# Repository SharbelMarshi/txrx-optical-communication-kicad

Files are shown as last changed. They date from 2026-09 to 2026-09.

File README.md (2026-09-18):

# A Free Space Optical Communication
This project implements a free-space optical communication link using two separate KiCad-designed boards: a transmitter and a receiver. The transmitter uses an RP2354A microcontroller to frame arbitrary digital payloads into packets and generate $100 \mathrm{kbit/s}$ RZ-OOK modulation for a $650 \mathrm{nm}$ laser module through a level-shifting buffer and an independent hardware safety chain.
The receiver uses a BPW34 photodiode, OPA320 transimpedance amplifier, and TLV3201 comparator to recover the optical pulses and feed them into an RP2354A for decoding, CRC verification, and delivery to the host system.
Both boards include USB-C, UART, SWD, a local $12 \mathrm{MHz}$ crystal, and a $10 \mathrm{MHz}$ SiTime SiT5346 DCTCXO reference. The SiT5346 is connected to the RP2354A through a GPIO/PIO clock input and is controllable over the existing $\text{I²C}$ bus. Each board also exposes a dedicated $1\mathrm{PPS}$ output generated by the RP2354A. The initial target is a stable free-space optical link over approximately $5$ meters.

## Architecture
Two separate $4$ layer boards:
- TX: RP2354A + USB-C + host I/O + $12 \mathrm{MHz}$ crystal + $10 \mathrm{MHz}$ SiT5346 DCTCXO + dedicated $1\mathrm{PPS}$ output + laser driver/safety chain + laser module.
- RX: RP2354A + USB-C + host I/O + $12 \mathrm{MHz}$ crystal + $10 \mathrm{MHz}$ SiT5346 DCTCXO + dedicated $1\mathrm{PPS}$ output + BPW34 / OPA320 / TLV3201 optical receiver + ADC monitor.

### TX
- TX_ROOT
- TX_POWER_USB
- TX_MCU_CLOCK
- TX_HOST_IO
- TX_LASER

### RX
- RX_ROOT
- RX_POWER_USB
- RX_MCU_CLOCK
- RX_HOST_IO
- RX_OPTICAL_AFE
- RX_MONITOR

### TX schamtics:

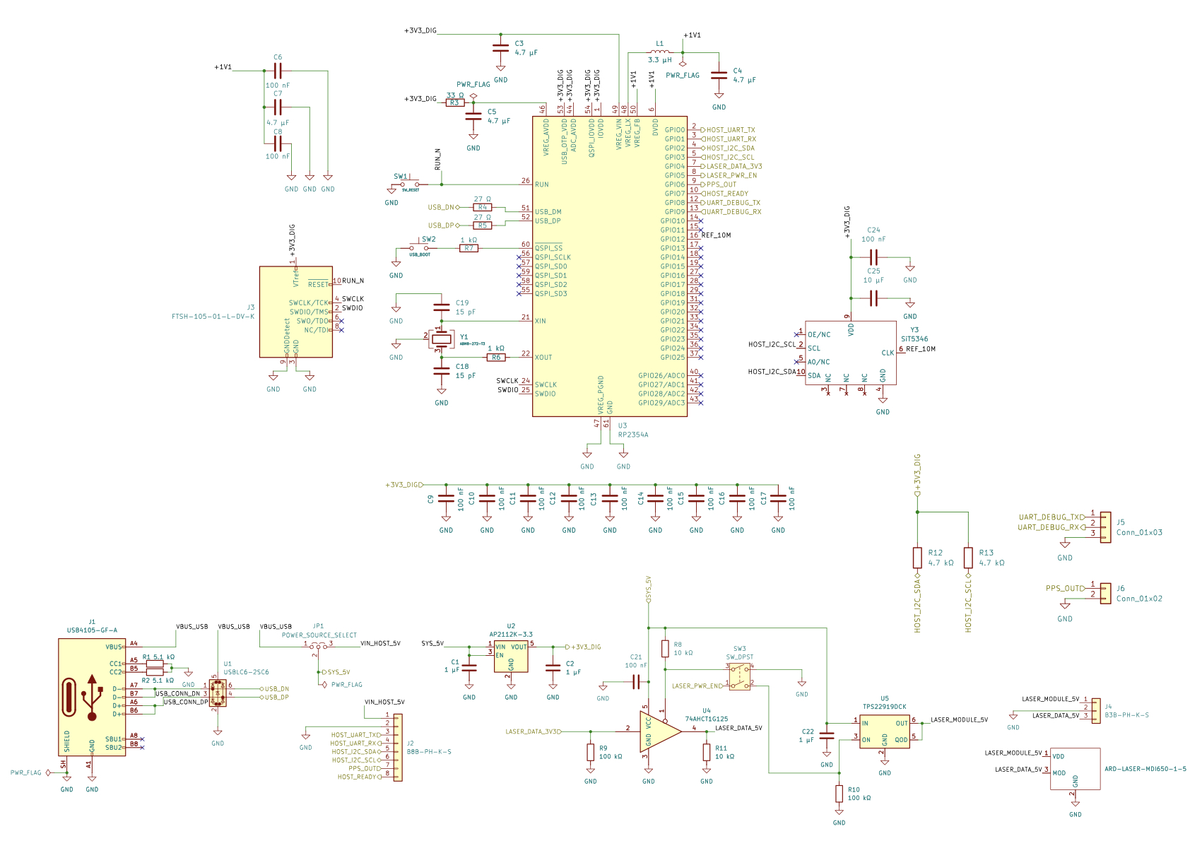
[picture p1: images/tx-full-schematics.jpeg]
schematics


### TX PCB: 

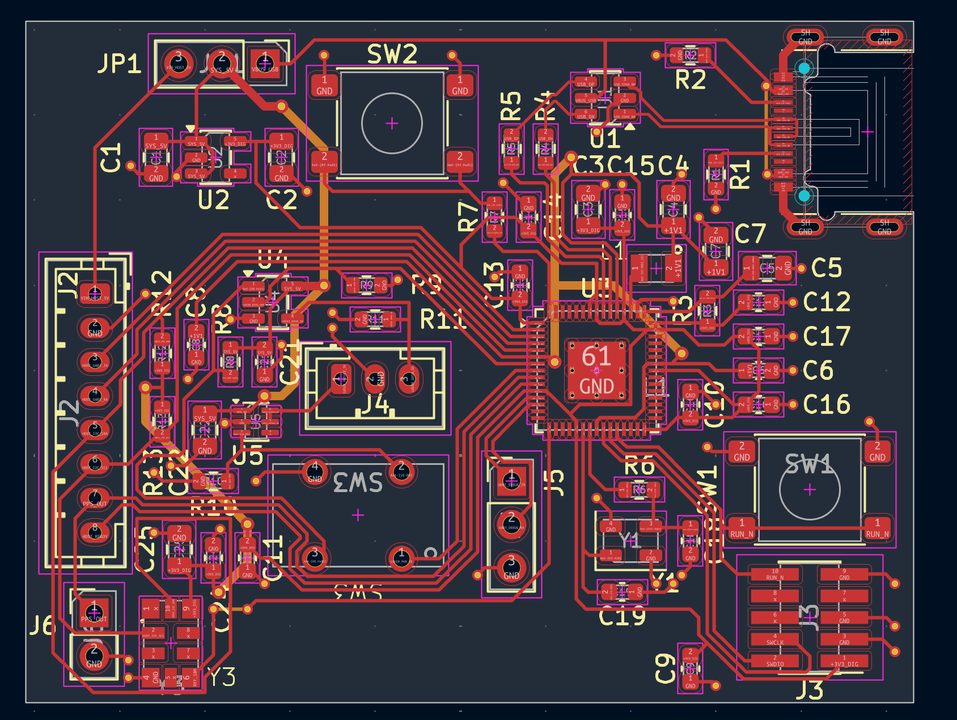
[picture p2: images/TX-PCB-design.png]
pcb design
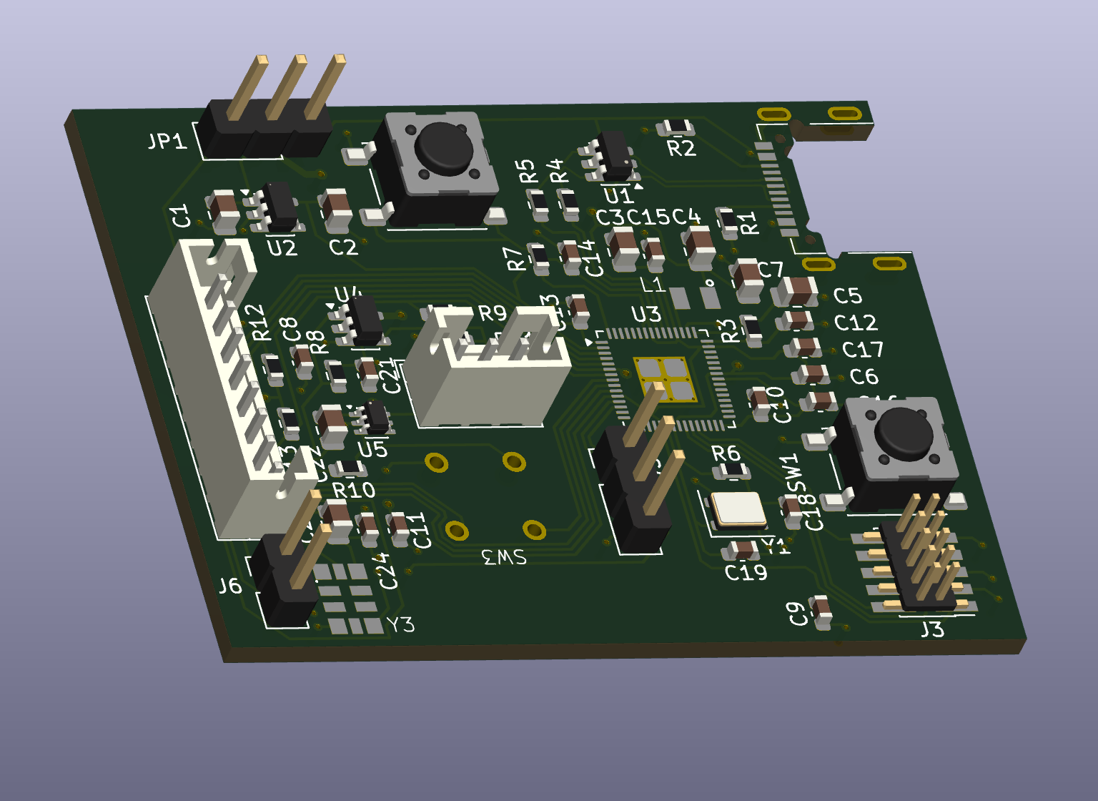
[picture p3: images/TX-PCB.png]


### RX schamtics:

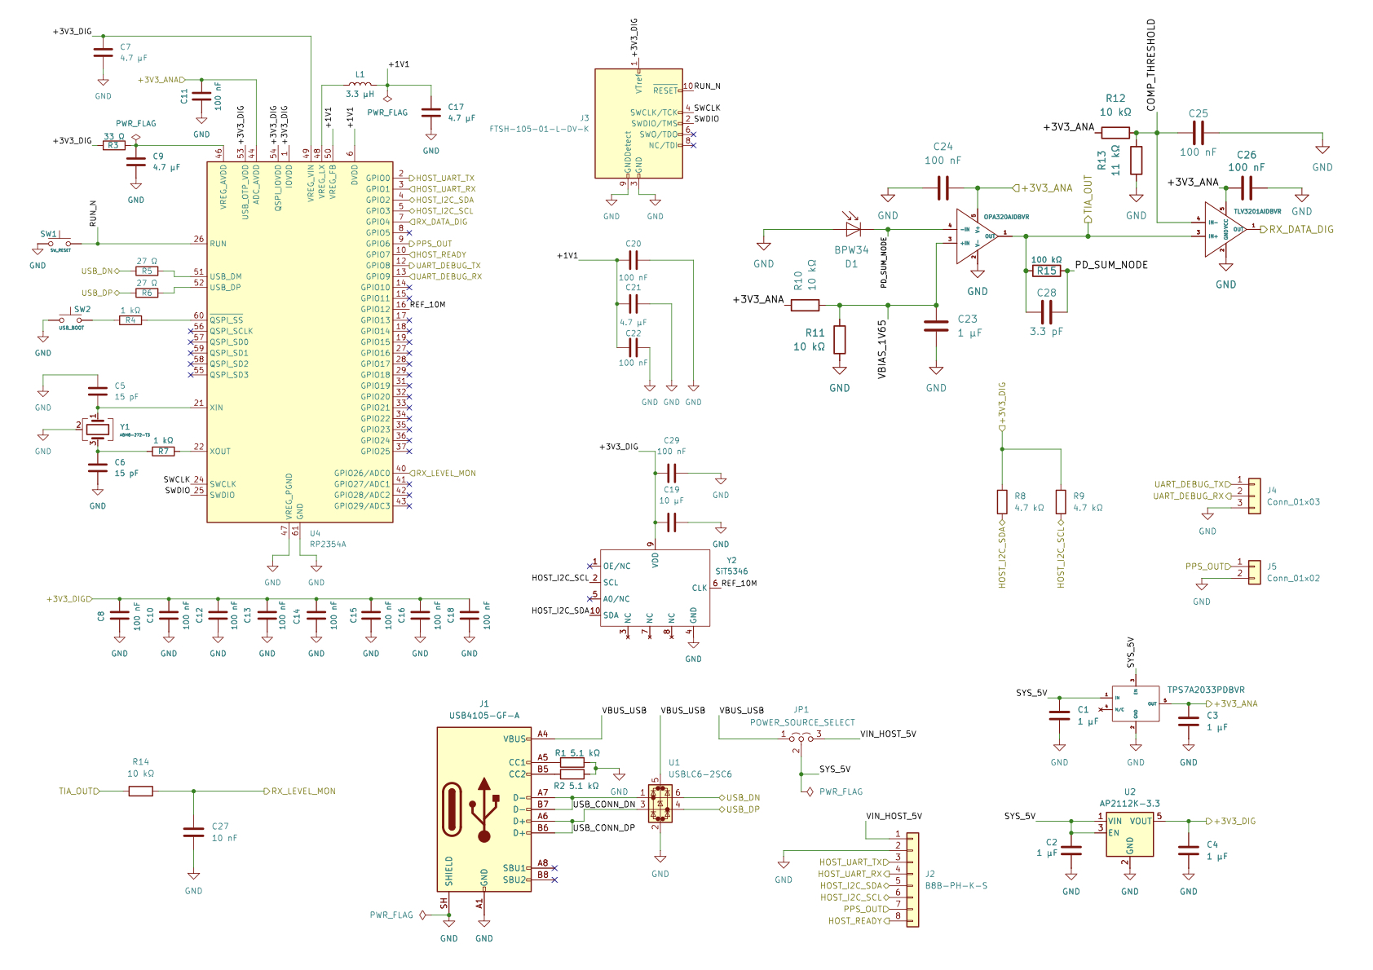
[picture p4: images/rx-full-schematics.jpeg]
schematics


### RX PCB: 

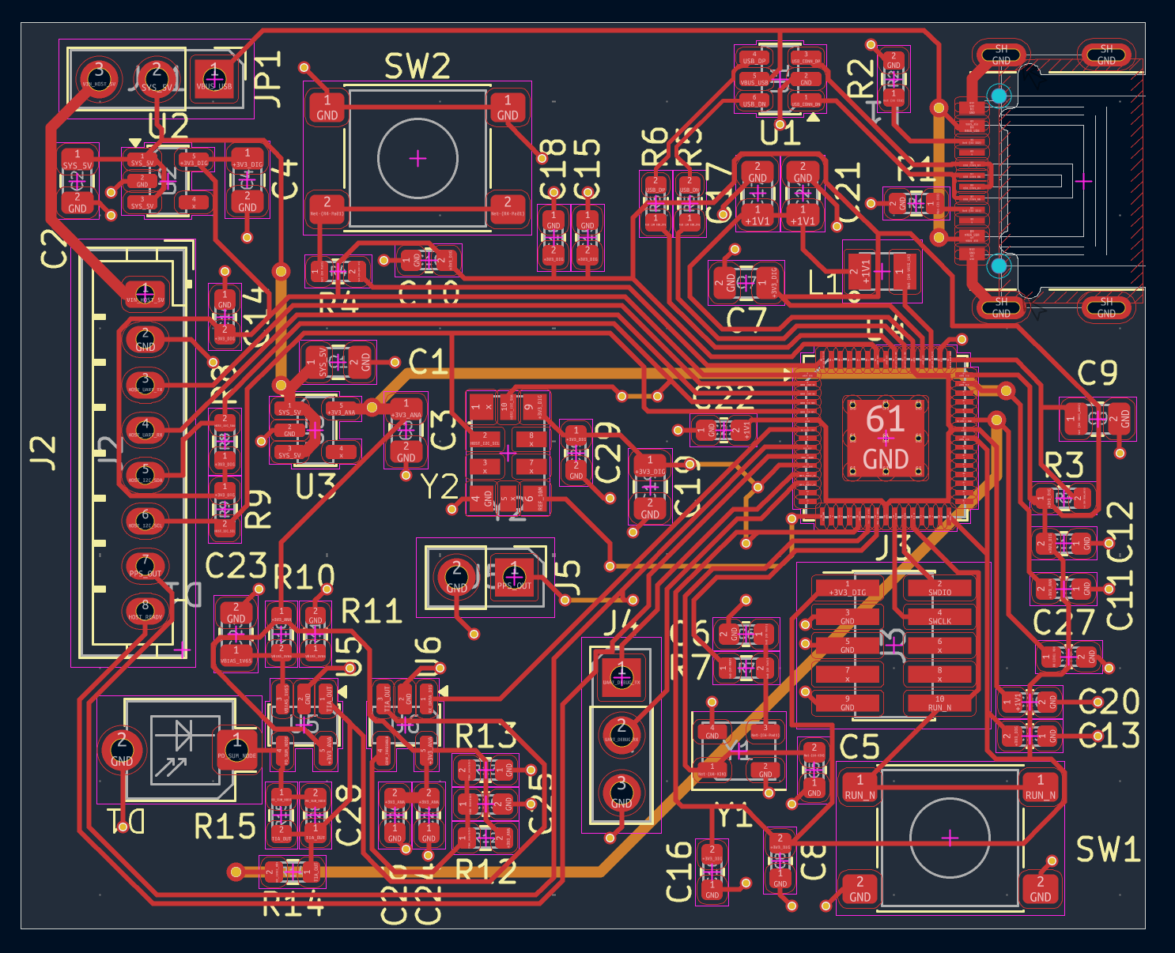
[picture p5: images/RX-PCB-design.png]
pcb design
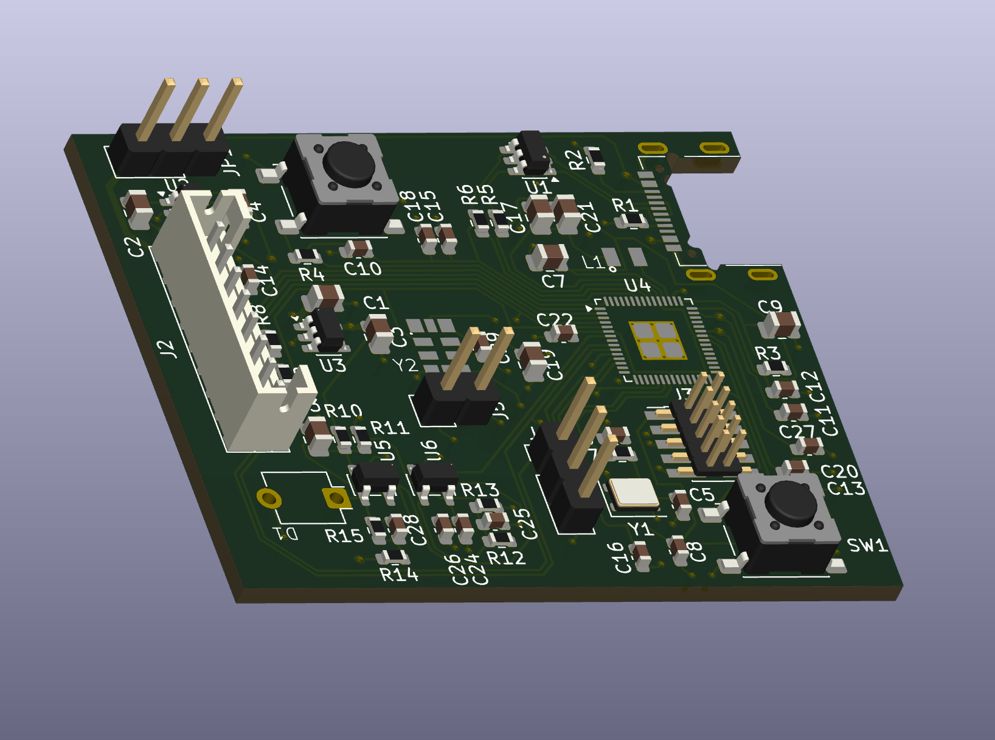
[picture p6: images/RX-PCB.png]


## Library:
### Pre-built Components Compatibility Verfication:

Verified: Symbol and Footprint compatibility: 

1. RP2354A  ✓
2. AP2112K-3.3  ✓
3. SN74AHCT1G125DBVR  ✓
4. TPS22919DCKR  ✓
5. USBLC6-2SC6  ✓
7. REF2033  ✓

### Costum Components:

1. SiT5346 ✓
2. OPA320  ✓
3. TLV3201 ✓
4. BPW34 (custom footprint)  ✓
5. TPS7A2033  (customed symbol) ✓
6. ABM8-272-T3_3225 (custom footprint)  ✓
7. AOTA-B201610S3R3-101-T (custom footprint) ✓
8. ES22MCBE (custom footprint) ✓
9. B3B-PH-K-S ✓
10. B8B-PH-K-S ✓
11. ARD-LASER-MDI650-1-5 ✓
12. FTSH-105-01-L-DV-K ✓
13. USB4105-GF-A ✓

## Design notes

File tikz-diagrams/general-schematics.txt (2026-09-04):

\usetikzlibrary{arrows.meta,positioning,fit}
\begin{tikzpicture}[
    font=\small,
    >=Latex,
    node distance=10mm and 18mm,
    block/.style={
        draw,
        rounded corners,
        thick,
        minimum width=34mm,
        minimum height=11mm,
        align=center
    },
    group/.style={
        draw,
        dashed,
        rounded corners,
        inner sep=6mm
    },
    arrow/.style={
        ->,
        thick
    }
]
\node[block] (hosttx) {Host System};
\node[block, below=of hosttx] (txmcu) {RP2354A Packet + PIO};
\node[block, below=of txmcu] (txbuf) {74AHCT1G125 Buffer};
\node[block, below=of txbuf] (laser) {650 nm Laser Module};
\node[block, right=75mm of hosttx] (hostrx) {Destination Host};
\node[block, below=of hostrx] (rxmcu) {RP2354A Decode + CRC};
\node[block, below=of rxmcu] (comp) {TLV3201 Comparator};
\node[block, below=of comp] (tia) {OPA320 TIA};
\node[block, below=of tia] (pd) {BPW34 Photodiode};
\draw[arrow] (hosttx) -- node[right] {data} (txmcu);
\draw[arrow] (txmcu) -- node[right] {100 kbit/s RZ-OOK} (txbuf);
\draw[arrow] (txbuf) -- (laser);
\draw[arrow, dashed, very thick]
(laser.east) -- node[above, rotate=-16] {Free-space optical link} (pd.west);
\draw[arrow] (pd) -- (tia);
\draw[arrow] (tia) -- (comp);
\draw[arrow] (comp) -- (rxmcu);
\draw[arrow] (rxmcu) -- node[right] {decoded data} (hostrx);
\node[
    group,
    fit=(hosttx)(txmcu)(txbuf)(laser),
    label=above:{\bfseries FSOC\_TX}
] {};

\node[
    group,
    fit=(hostrx)(rxmcu)(comp)(tia)(pd),
    label=above:{\bfseries FSOC\_RX}
] {};
\end{tikzpicture}

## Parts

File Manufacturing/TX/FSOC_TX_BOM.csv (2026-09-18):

Reference | Qty | Value | Footprint | Manufacturer | Description | MPN | JLCPCB Part
C1,C2,C22 | 3 | 1 µF | Capacitor_SMD:C_0805_2012Metric |  | Unpolarized capacitor
C3,C4,C5,C7 | 4 | 4.7 µF | Capacitor_SMD:C_0805_2012Metric |  | Unpolarized capacitor
C6,C8,C9,C10,C11,C12,C13,C14,C15,C16,C17,C21,C24 | 13 | 100 nF | Capacitor_SMD:C_0603_1608Metric |  | Unpolarized capacitor
C18,C19 | 2 | 15 pF | Capacitor_SMD:C_0603_1608Metric |  | Unpolarized capacitor
C25 | 1 | 10 µF | Capacitor_SMD:C_0805_2012Metric |  | Unpolarized capacitor
J1 | 1 | USB4105-GF-A | fsoc_footprints:TYPE-C-31-M-14 | GCT | USB 2.0 Type-C receptacle, 16 contact, top-mount horizontal, through-hole shell stakes | USB4105-GF-A
J2 | 1 | B8B-PH-K-S | Connector_JST:JST_PH_B8B-PH-K_1x08_P2.00mm_Vertical | JST | 8-position JST PH series vertical through-hole wire-to-board header, 2.00 mm pitch | B8B-PH-K-S
J3 | 1 | FTSH-105-01-L-DV-K | fsoc_footprints:FTSH-105-01-L-DV-K | Samtec | 10-pin 1.27 mm keyed vertical SMT header for ARM Cortex SWD/JTAG debug interface | FTSH-105-01-L-DV-K
J4 | 1 | B3B-PH-K-S | Connector_JST:JST_PH_B3B-PH-K_1x03_P2.00mm_Vertical | JST | 3-position JST PH series vertical through-hole wire-to-board header, 2.00 mm pitch | B3B-PH-K-S
J5 | 1 | Conn_01x03 | Connector_PinHeader_2.54mm:PinHeader_1x03_P2.54mm_Vertical |  | Generic connector, single row, 01x03, script generated (kicad-library-utils/schlib/autogen/connector/)
J6 | 1 | Conn_01x02 | Connector_PinHeader_2.54mm:PinHeader_1x02_P2.54mm_Vertical |  | Generic connector, single row, 01x02, script generated (kicad-library-utils/schlib/autogen/connector/)
L1 | 1 | 3.3 µH | fsoc_footprints:AOTA-B201610S3R3-101-T |  | Inductor
MOD1 | 1 | ARD-LASER-MDI650-1-5 |  | Picotronic GmbH | 650 nm 1 mW Class 2 laser module, 5 V, active-high TTL modulation up to 200 kHz | ARD-LASER-MDI650-1-5(10x26)
R1,R2 | 2 | 5.1 kΩ | Resistor_SMD:R_0603_1608Metric |  | Resistor
R3 | 1 | 33 Ω | Resistor_SMD:R_0603_1608Metric |  | Resistor
R4,R5 | 2 | 27 Ω | Resistor_SMD:R_0603_1608Metric |  | Resistor
R6,R7 | 2 | 1 kΩ | Resistor_SMD:R_0603_1608Metric |  | Resistor
R8,R11 | 2 | 10 kΩ | Resistor_SMD:R_0603_1608Metric |  | Resistor
R9,R10 | 2 | 100 kΩ | Resistor_SMD:R_0603_1608Metric |  | Resistor
R12,R13 | 2 | 4.7 kΩ | Resistor_SMD:R_0603_1608Metric |  | Resistor
SW1 | 1 | SW_RESET | Button_Switch_SMD:SW_SPST_PTS645Sx43SMTR92 |  | Push button switch, generic, two pins
SW2 | 1 | USB_BOOT | Button_Switch_SMD:SW_SPST_PTS645Sx43SMTR92 |  | Push button switch, generic, two pins
SW3 | 1 | SW_DPST | fsoc_footprints:ES22MCBE |  | Double Pole Single Throw (DPST) Switch
U1 | 1 | USBLC6-2SC6 | Package_TO_SOT_SMD:SOT-23-6 |  | Very low capacitance ESD protection diode, 2 data-line, SOT-23-6
U2 | 1 | AP2112K-3.3 | Package_TO_SOT_SMD:SOT-23-5 |  | 600mA low dropout linear regulator, with enable pin, 3.8V-6V input voltage range, 3.3V fixed positive output, SOT-23-5
U3 | 1 | RP2354A | Package_DFN_QFN:QFN-60-1EP_7x7mm_P0.4mm_EP3.4x3.4mm_ThermalVias |  | A microcontroller by Raspberry Pi, dual CPU architecture (ARM Cortex-M33 / RISC-V Hazard3), 150MHz, 2MB flash, 520KB SRAM, 12 PIO state machines, VQFN-60
U4 | 1 | 74AHCT1G125 | Package_TO_SOT_SMD:SOT-23-5 |  | Single Buffer Gate Tri-State, Low-Voltage CMOS
U5 | 1 | TPS22919DCK | Package_TO_SOT_SMD:SOT-363_SC-70-6 |  | 1.6V to 5.5 V, 1.5 A, 90-mΩ Self-Protected Load Switch with Controlled Rise Time, SC-70-6
Y1 | 1 | ABM8-272-T3 | fsoc_footprints:ABM8-272-T3_3225 | Abracon | 12 MHz crystal, 10 pF load capacitance, 50 ohm max ESR, 3.2 x 2.5 mm 4-pad SMD | ABM8-272-T3
Y3 | 1 | SiT5346 | fsoc_footprints:SiT5346_5.0x3.2mm_10L | SiTime | SiT5346 DCTCXO, 10.000000 MHz, 3.3 V, LVCMOS, ±0.1 ppm, industrial, I2C-controlled | TBD - SiT5346 10MHz 3.3V LVCMOS DCTCXO | TBD - Global Sourcing if not stocked

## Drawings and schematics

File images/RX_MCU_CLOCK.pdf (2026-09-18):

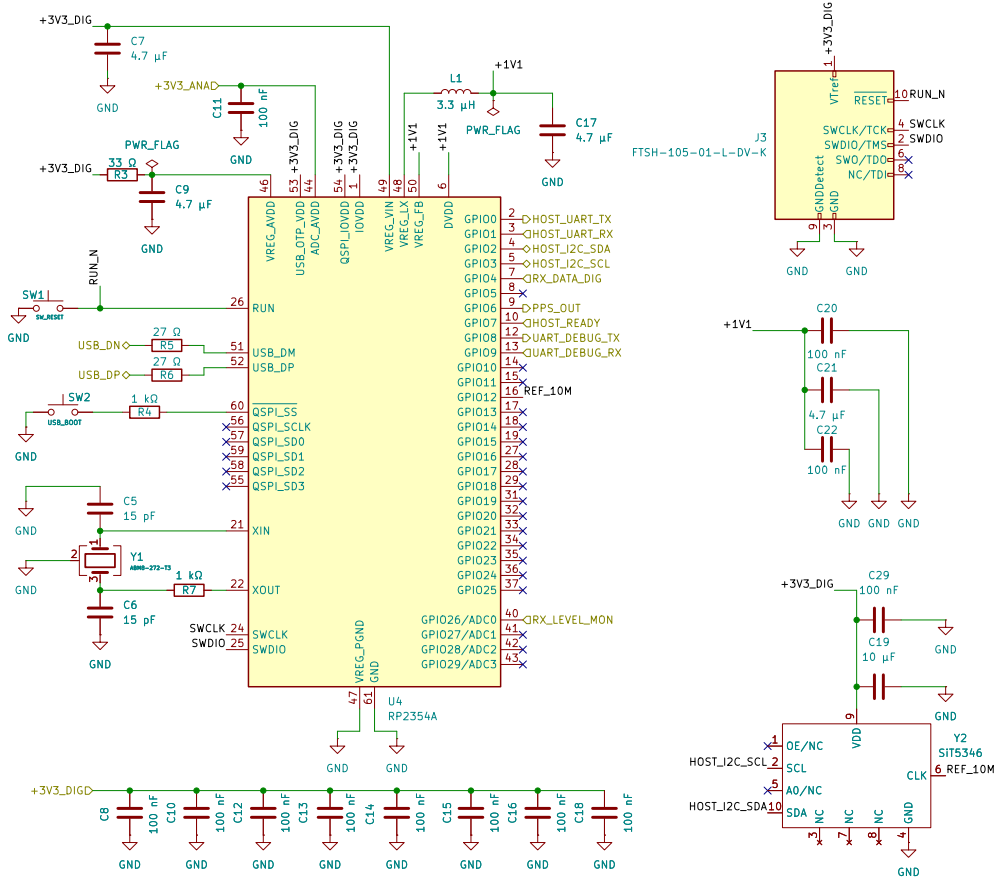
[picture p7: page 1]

100 nF GND GND GND

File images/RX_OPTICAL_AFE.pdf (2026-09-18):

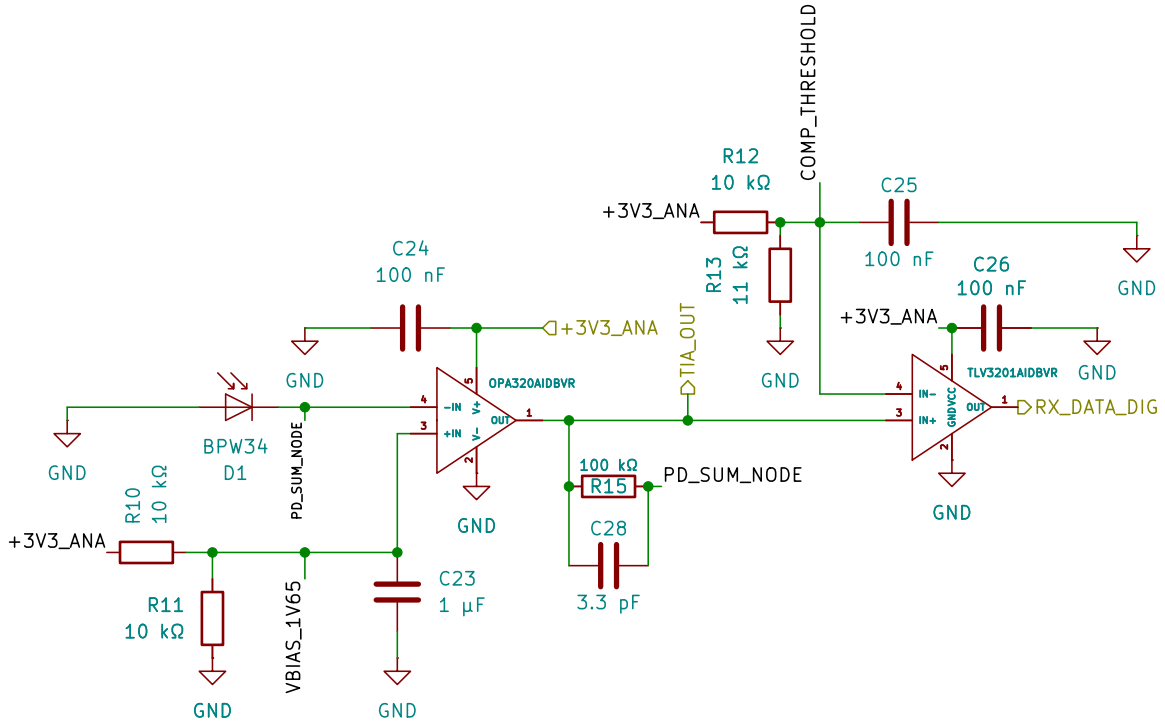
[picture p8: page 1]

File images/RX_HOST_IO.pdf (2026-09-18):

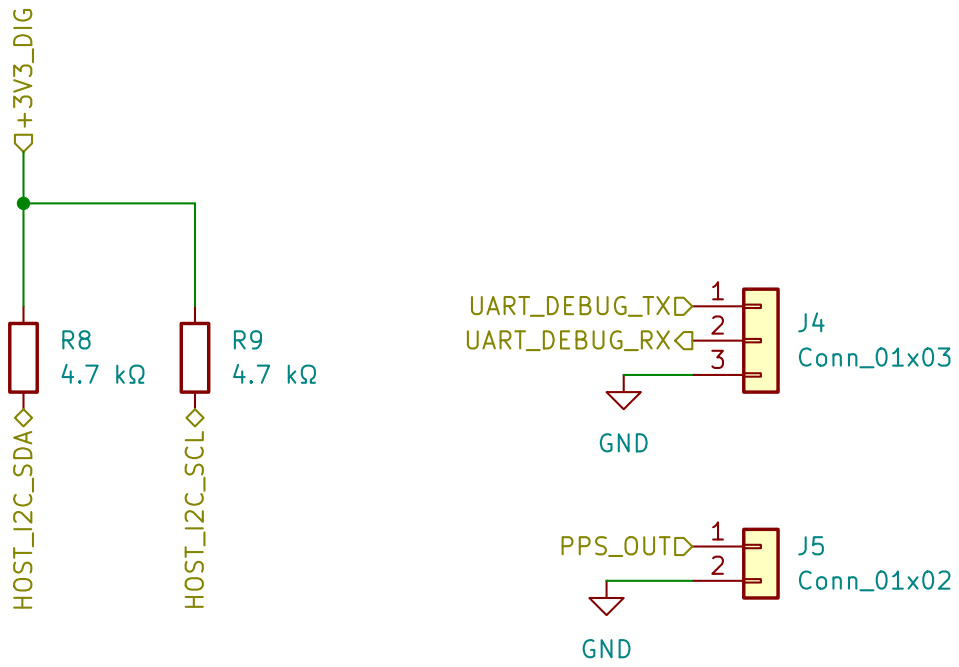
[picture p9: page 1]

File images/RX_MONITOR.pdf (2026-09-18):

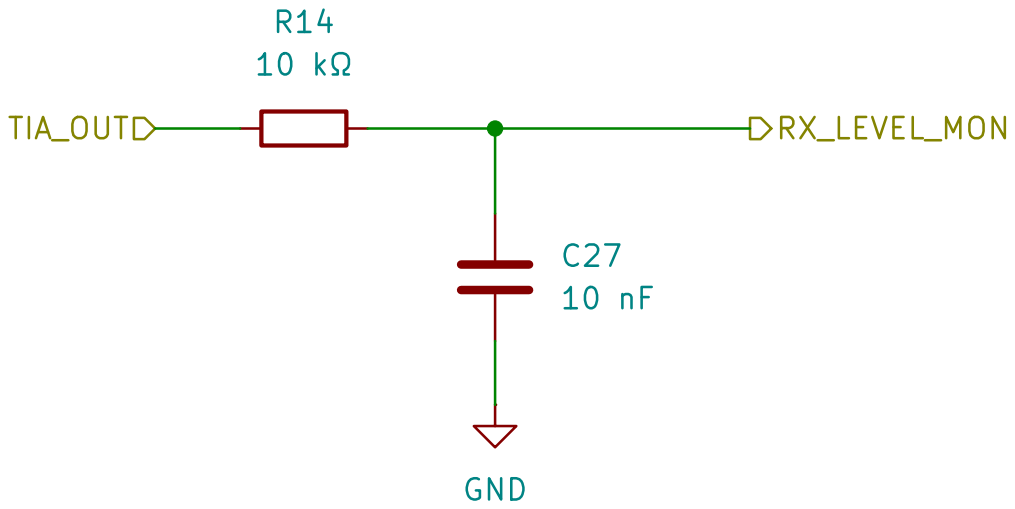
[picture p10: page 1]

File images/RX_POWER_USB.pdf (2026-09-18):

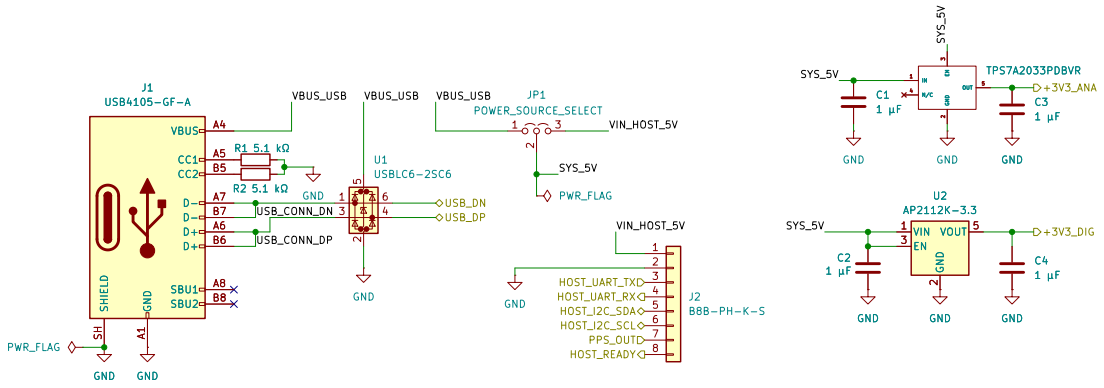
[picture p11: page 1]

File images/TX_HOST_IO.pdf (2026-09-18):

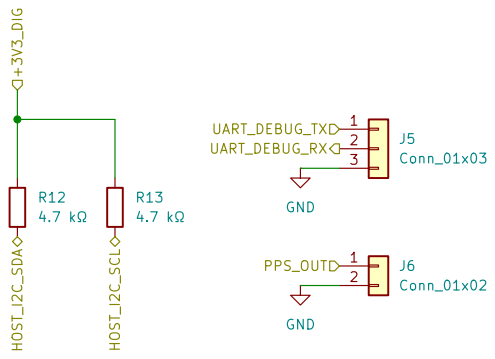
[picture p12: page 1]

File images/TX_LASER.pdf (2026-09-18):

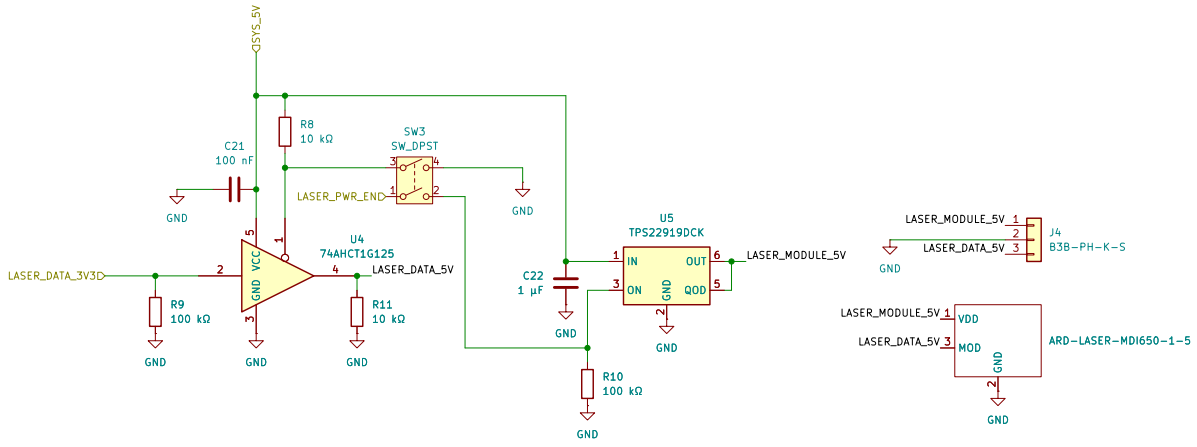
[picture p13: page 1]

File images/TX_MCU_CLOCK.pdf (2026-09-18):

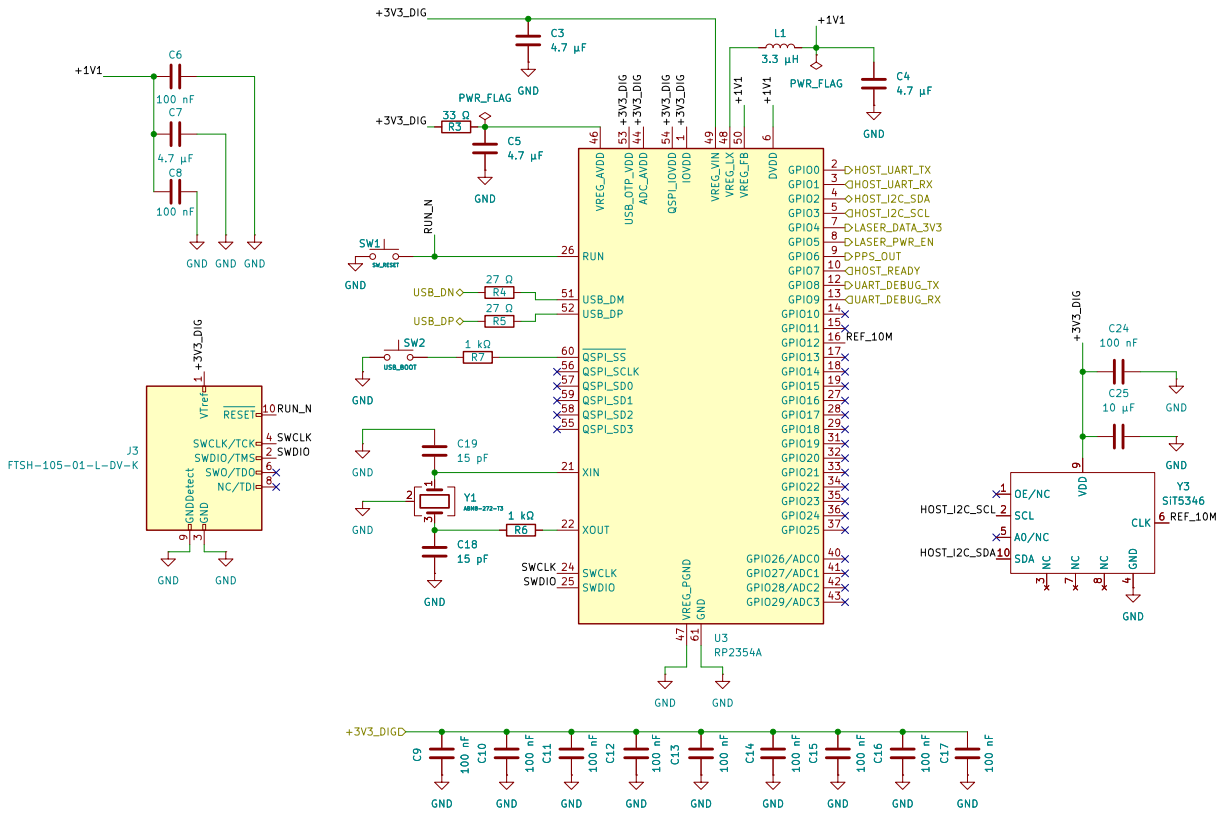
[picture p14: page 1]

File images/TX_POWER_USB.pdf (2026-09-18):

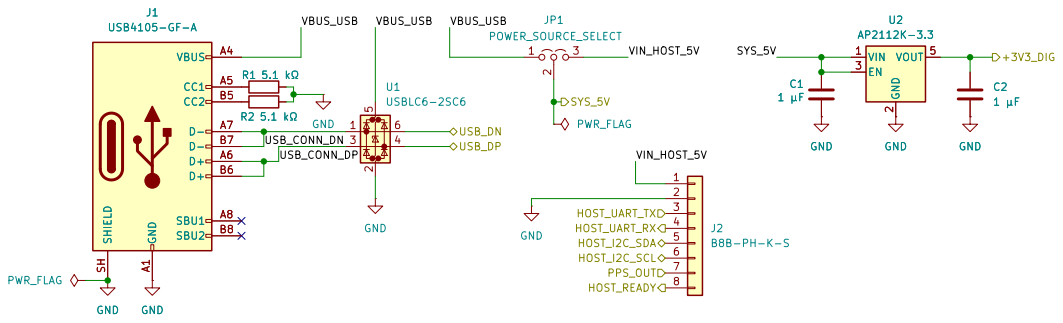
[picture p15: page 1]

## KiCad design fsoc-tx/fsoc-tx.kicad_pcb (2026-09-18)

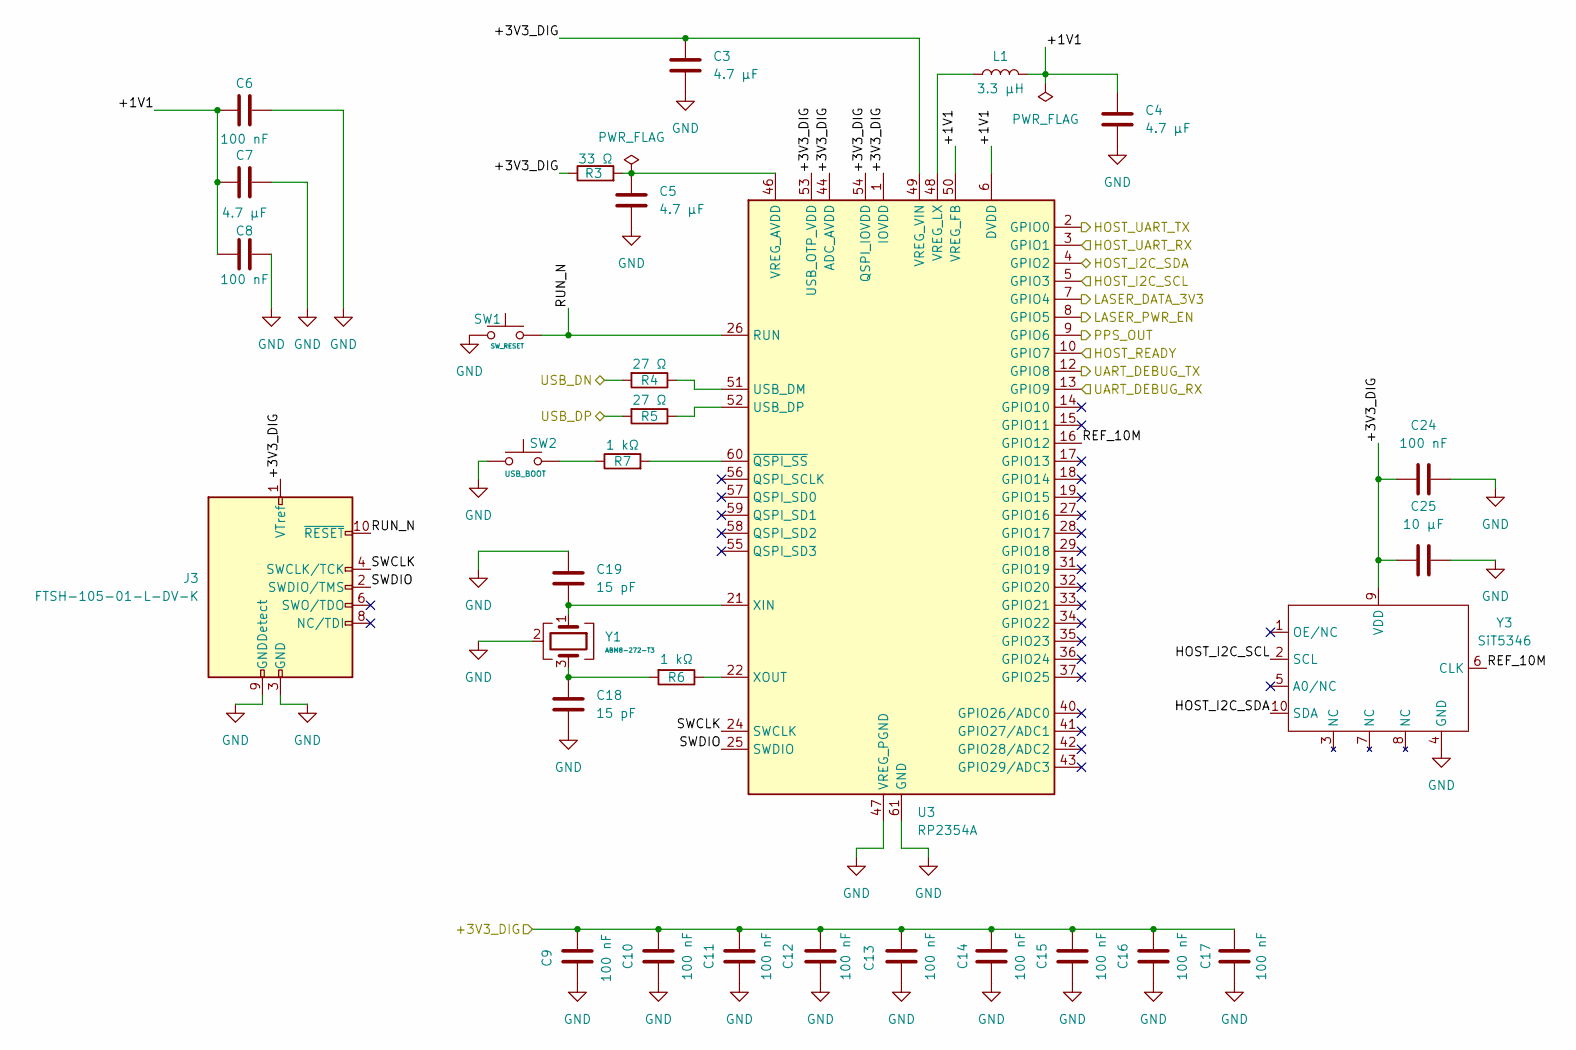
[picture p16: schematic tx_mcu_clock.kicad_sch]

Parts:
C3, C4, C5, C7: 4.7 µF; C_0805_2012Metric
C6, C8, C9, C10, C11, C12, C13, C14, C15, C16, C17, C24: 100 nF; C_0603_1608Metric
C18, C19: 15 pF; C_0603_1608Metric
C25: 10 µF; C_0805_2012Metric
J3: FTSH-105-01-L-DV-K; MPN FTSH-105-01-L-DV-K
L1: 3.3 µH; AOTA-B201610S3R3-101-T
R3: 33 Ω; R_0603_1608Metric
R4, R5: 27 Ω; R_0603_1608Metric
R6, R7: 1 kΩ; R_0603_1608Metric
SW1: SW_RESET; SW_SPST_PTS645Sx43SMTR92
SW2: USB_BOOT; SW_SPST_PTS645Sx43SMTR92
U3: RP2354A; QFN-60-1EP_7x7mm_P0.4mm_EP3.4x3.4mm_ThermalVias
Y1: ABM8-272-T3; ABM8-272-T3_3225; MPN ABM8-272-T3
Y3: SiT5346; SiT5346_5.0x3.2mm_10L; MPN TBD - SiT5346 10MHz 3.3V LVCMOS DCTCXO; JLCPCB Part TBD - Global Sourcing if not stocked

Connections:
/+3V3_DIG: C3.1, C9.2, C10.2, C11.2, C12.2, C13.2, C14.2, C15.2, C16.2, C17.2, C24.1, C25.1, J3.1 (VTref), R3.1, U3.1 (IOVDD), U3.11 (IOVDD), U3.20 (IOVDD), U3.30 (IOVDD), U3.38 (IOVDD), U3.44 (ADC_AVDD), U3.45 (IOVDD), U3.49 (VREG_VIN), U3.53 (USB_OTP_VDD), U3.54 (QSPI_IOVDD), Y3.9 (VDD); also elsewhere on the board
/HOST_I2C_SCL: U3.5 (GPIO3), Y3.2 (SCL); also elsewhere on the board
/HOST_I2C_SDA: U3.4 (GPIO2), Y3.10 (SDA); also elsewhere on the board
/HOST_READY: U3.10 (GPIO7); also elsewhere on the board
/HOST_UART_RX: U3.3 (GPIO1); also elsewhere on the board
/HOST_UART_TX: U3.2 (GPIO0); also elsewhere on the board
/LASER_DATA_3V3: U3.7 (GPIO4); also elsewhere on the board
/LASER_PWR_EN: U3.8 (GPIO5); also elsewhere on the board
/PPS_OUT: U3.9 (GPIO6); also elsewhere on the board
/TX_MCU_CLOCK/+1V1: C4.1, C6.1, C7.1, C8.2, L1.2, U3.6 (DVDD), U3.23 (DVDD), U3.39 (DVDD), U3.50 (VREG_FB)
/TX_MCU_CLOCK/REF_10M: U3.16 (GPIO12), Y3.6 (CLK)
/TX_MCU_CLOCK/RUN_N: J3.10 (~RESET), SW1.1, U3.26 (RUN)
/TX_MCU_CLOCK/SWCLK: J3.4 (SWCLK/TCK), U3.24 (SWCLK)
/TX_MCU_CLOCK/SWDIO: J3.2 (SWDIO/TMS), U3.25 (SWDIO)
/UART_DEBUG_RX: U3.13 (GPIO9); also elsewhere on the board
/UART_DEBUG_TX: U3.12 (GPIO8); also elsewhere on the board
/USB_DN: R4.2; also elsewhere on the board
/USB_DP: R5.2; also elsewhere on the board
GND: C3.2, C4.2, C5.2, C6.2, C7.2, C8.1, C9.1, C10.1, C11.1, C12.1, C13.1, C14.1, C15.1, C16.1, C17.1, C18.2, C19.1, C24.2, C25.2, J3.3 (GND), J3.5 (GND), J3.9 (GNDDetect), SW1.2, SW2.1, U3.47 (VREG_PGND), U3.61 (GND), Y1.2 (G), Y1.4 (G), Y3.4 (GND); also elsewhere on the board
unnamed: C18.1, R6.2, Y1.3
unnamed: R7.1, SW2.2
unnamed: R4.1, U3.51 (USB_DM)
unnamed: R5.1, U3.52 (USB_DP)
unnamed: C5.1, R3.2, U3.46 (VREG_AVDD)
unnamed: L1.1, U3.48 (VREG_LX)
unnamed: C19.2, U3.21 (XIN), Y1.1
unnamed: R6.1, U3.22 (XOUT)
unnamed: R7.2, U3.60 (~QSPI_SS)

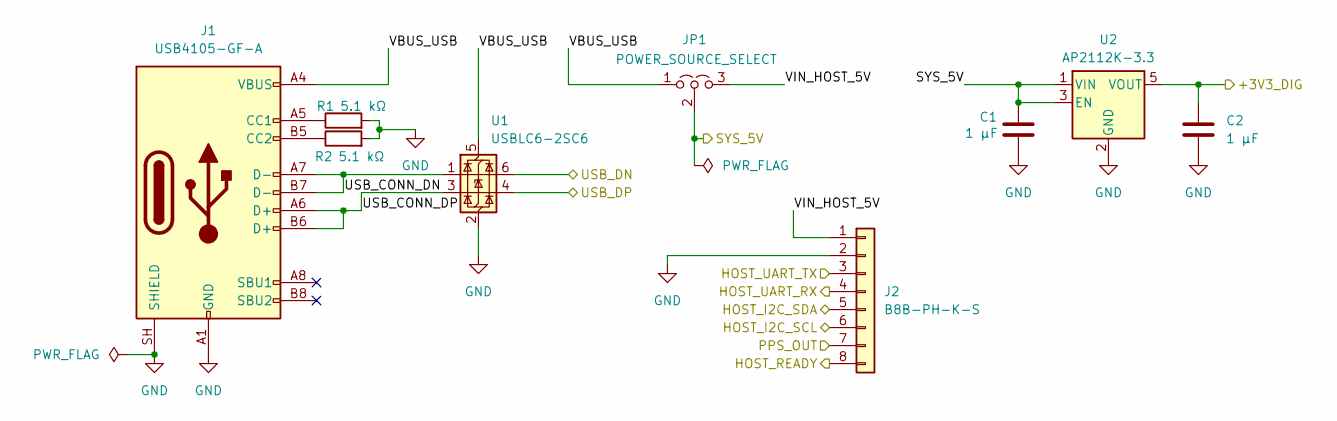
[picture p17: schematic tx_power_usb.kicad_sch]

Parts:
C1, C2: 1 µF; C_0805_2012Metric
J1: USB4105-GF-A; TYPE-C-31-M-14; MPN USB4105-GF-A
J2: B8B-PH-K-S; JST_PH_B8B-PH-K_1x08_P2.00mm_Vertical; MPN B8B-PH-K-S
JP1: POWER_SOURCE_SELECT; PinHeader_1x03_P2.54mm_Vertical; MPN TSW-103-07-G-S
R1, R2: 5.1 kΩ; R_0603_1608Metric
U1: USBLC6-2SC6; SOT-23-6
U2: AP2112K-3.3; SOT-23-5

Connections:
/+3V3_DIG: C2.1, U2.5 (VOUT); also elsewhere on the board
/HOST_I2C_SCL: J2.6; also elsewhere on the board
/HOST_I2C_SDA: J2.5; also elsewhere on the board
/HOST_READY: J2.8; also elsewhere on the board
/HOST_UART_RX: J2.4; also elsewhere on the board
/HOST_UART_TX: J2.3; also elsewhere on the board
/PPS_OUT: J2.7; also elsewhere on the board
/SYS_5V: C1.1, JP1.2 (C), U2.1 (VIN), U2.3 (EN); also elsewhere on the board
/TX_POWER_USB/USB_CONN_DN: J1.A7 (D-), J1.B7 (D-), U1.1 (I/O1)
/TX_POWER_USB/USB_CONN_DP: J1.A6 (D+), J1.B6 (D+), U1.3 (I/O2)
/TX_POWER_USB/VBUS_USB: J1.A4 (VBUS), J1.A9 (VBUS), J1.B4 (VBUS), J1.B9 (VBUS), JP1.1 (A), U1.5 (VBUS)
/TX_POWER_USB/VIN_HOST_5V: J2.1, JP1.3 (B)
/USB_DN: U1.6 (I/O1); also elsewhere on the board
/USB_DP: U1.4 (I/O2); also elsewhere on the board
GND: C1.2, C2.2, J1.A1 (GND), J1.A12 (GND), J1.B1 (GND), J1.B12 (GND), J1.SH (SHIELD), J2.2, R1.2, R2.2, U1.2 (GND), U2.2 (GND); also elsewhere on the board
unnamed: J1.A5 (CC1), R1.1
unnamed: J1.B5 (CC2), R2.1

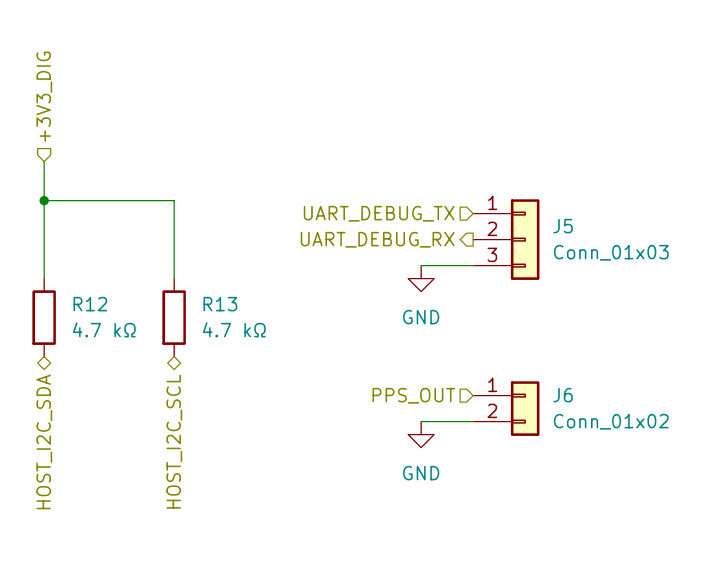
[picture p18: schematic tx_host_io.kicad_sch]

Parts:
J5: Conn_01x03; PinHeader_1x03_P2.54mm_Vertical
J6: Conn_01x02; PinHeader_1x02_P2.54mm_Vertical
R12, R13: 4.7 kΩ; R_0603_1608Metric

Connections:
/+3V3_DIG: R12.1, R13.1; also elsewhere on the board
/HOST_I2C_SCL: R13.2; also elsewhere on the board
/HOST_I2C_SDA: R12.2; also elsewhere on the board
/PPS_OUT: J6.1; also elsewhere on the board
/UART_DEBUG_RX: J5.2; also elsewhere on the board
/UART_DEBUG_TX: J5.1; also elsewhere on the board
GND: J5.3, J6.2; also elsewhere on the board

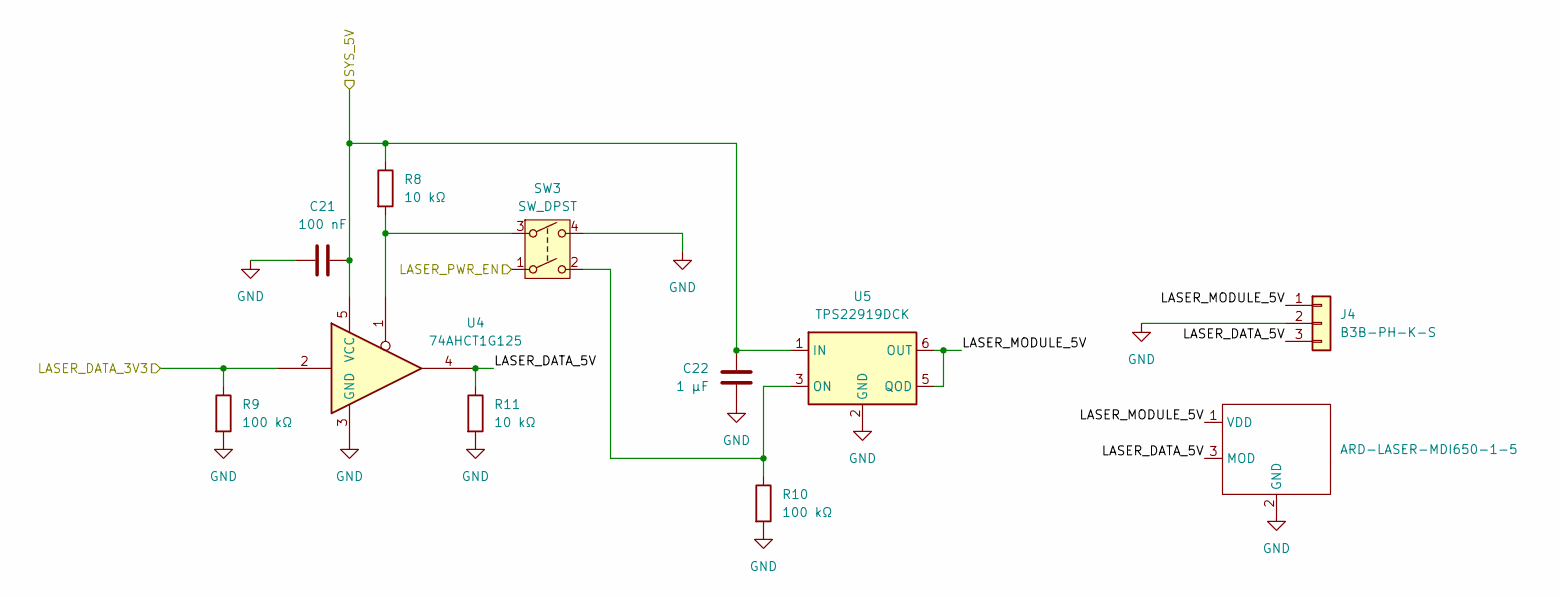
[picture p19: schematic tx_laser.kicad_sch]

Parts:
C21: 100 nF; C_0603_1608Metric
C22: 1 µF; C_0805_2012Metric
J4: B3B-PH-K-S; JST_PH_B3B-PH-K_1x03_P2.00mm_Vertical; MPN B3B-PH-K-S
MOD1: ARD-LASER-MDI650-1-5; MPN ARD-LASER-MDI650-1-5(10x26)
R8, R11: 10 kΩ; R_0603_1608Metric
R9, R10: 100 kΩ; R_0603_1608Metric
SW3: SW_DPST; ES22MCBE
U4: 74AHCT1G125; SOT-23-5
U5: TPS22919DCK; SOT-363_SC-70-6

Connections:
/LASER_DATA_3V3: R9.1, U4.2; also elsewhere on the board
/LASER_PWR_EN: SW3.1; also elsewhere on the board
/SYS_5V: C21.2, C22.1, R8.1, U4.5 (VCC), U5.1 (IN); also elsewhere on the board
/TX_LASER/LASER_DATA_5V: J4.3, MOD1.3 (MOD), R11.1, U4.4
/TX_LASER/LASER_MODULE_5V: J4.1, MOD1.1 (VDD), U5.5 (QOD), U5.6 (OUT)
GND: C21.1, C22.2, J4.2, MOD1.2 (GND), R9.2, R10.2, R11.2, SW3.4, U4.3 (GND), U5.2 (GND); also elsewhere on the board
unnamed: R8.2, SW3.3, U4.1
unnamed: R10.1, SW3.2, U5.3 (ON)

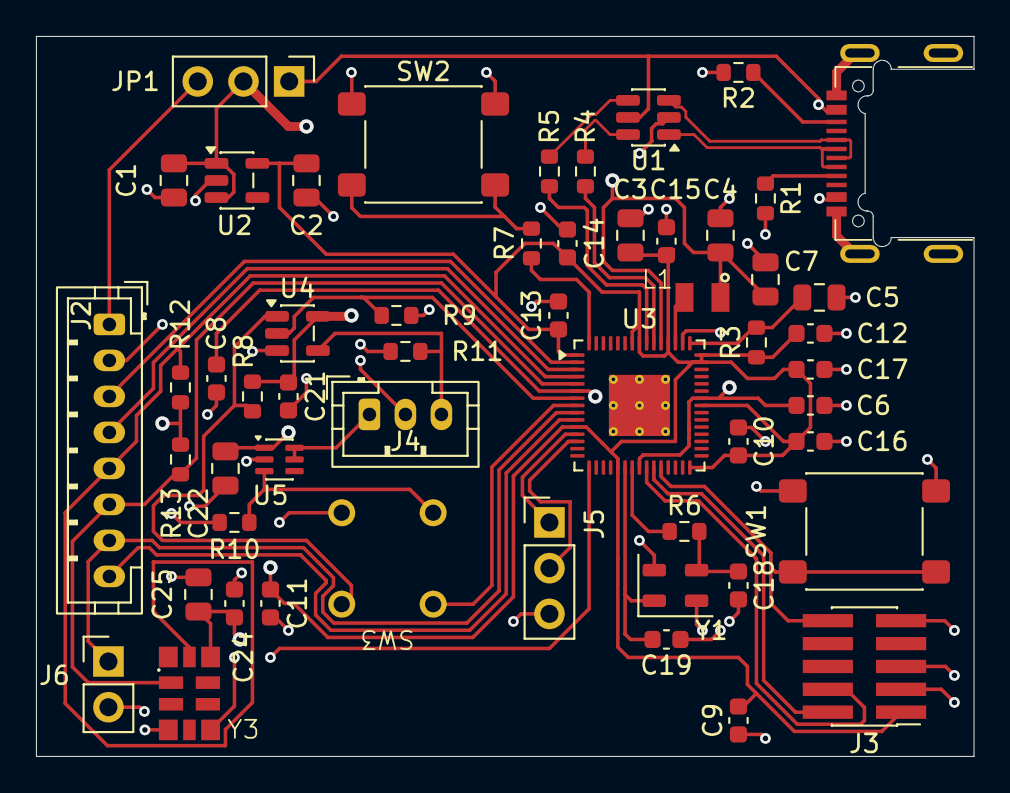
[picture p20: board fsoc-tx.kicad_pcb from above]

Board: 4 copper layers, 52.1 x 40.0 mm, 54 parts (0 on the bottom side), 39 nets.

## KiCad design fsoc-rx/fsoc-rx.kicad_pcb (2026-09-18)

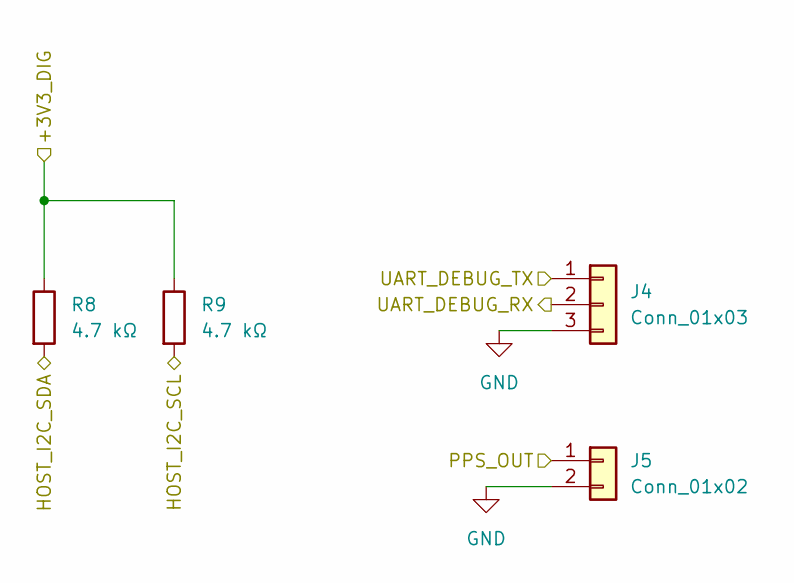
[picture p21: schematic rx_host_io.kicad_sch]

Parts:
J4: Conn_01x03; PinHeader_1x03_P2.54mm_Vertical
J5: Conn_01x02; PinHeader_1x02_P2.54mm_Vertical
R8, R9: 4.7 kΩ; R_0603_1608Metric

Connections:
/+3V3_DIG: R8.1, R9.1; also elsewhere on the board
/HOST_I2C_SCL: R9.2; also elsewhere on the board
/HOST_I2C_SDA: R8.2; also elsewhere on the board
/PPS_OUT: J5.1; also elsewhere on the board
/UART_DEBUG_RX: J4.2; also elsewhere on the board
/UART_DEBUG_TX: J4.1; also elsewhere on the board
GND: J4.3, J5.2; also elsewhere on the board

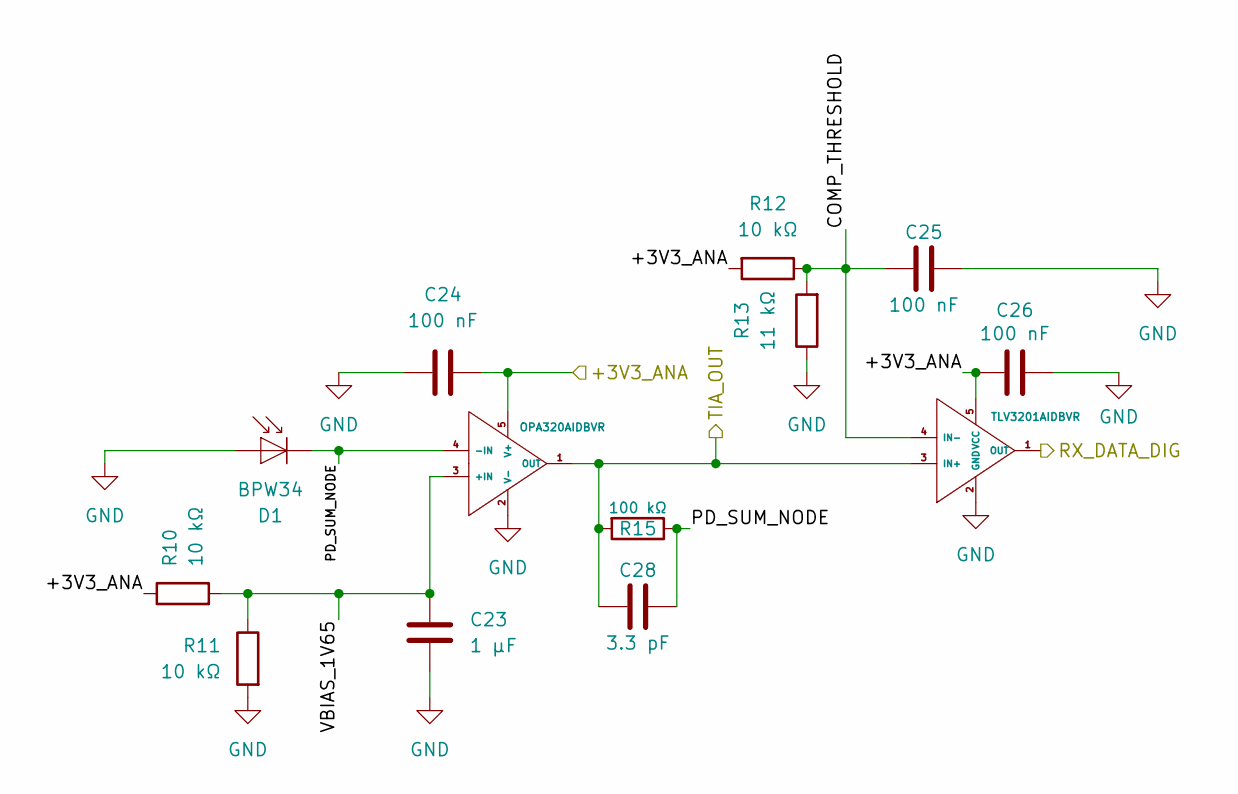
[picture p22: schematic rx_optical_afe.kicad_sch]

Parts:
C23: 1 µF; C_0805_2012Metric
C24, C25, C26: 100 nF; C_0603_1608Metric
C28: 3.3 pF; C_0603_1608Metric
D1: BPW34; BPW34_Vishay; MPN BPW34
R10, R11, R12: 10 kΩ; R_0603_1608Metric
R13: 11 kΩ; R_0603_1608Metric
R15: 100 kΩ; R_0603_1608Metric
U5: OPA320AIDBVR; SOT-23-5; MPN OPA320AIDBVR
U6: TLV3201AIDBVR; SOT-23-5; MPN TLV3201AIDBVR

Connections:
/+3V3_ANA: C24.2, C26.2, R10.1, R12.2, U5.5 (V+), U6.5 (VCC); also elsewhere on the board
/RX_DATA_DIG: U6.1 (OUT); also elsewhere on the board
/RX_OPTICAL_AFE/COMP_THRESHOLD: C25.1, R12.1, R13.2, U6.4 (IN-)
/RX_OPTICAL_AFE/PD_SUM_NODE: C28.2, D1.1 (K), R15.1, U5.4 (-IN)
/RX_OPTICAL_AFE/VBIAS_1V65: C23.1, R10.2, R11.1, U5.3 (+IN)
/TIA_OUT: C28.1, R15.2, U5.1 (OUT), U6.3 (IN+); also elsewhere on the board
GND: C23.2, C24.1, C25.2, C26.1, D1.2 (A), R11.2, R13.1, U5.2 (V-), U6.2 (GND); also elsewhere on the board

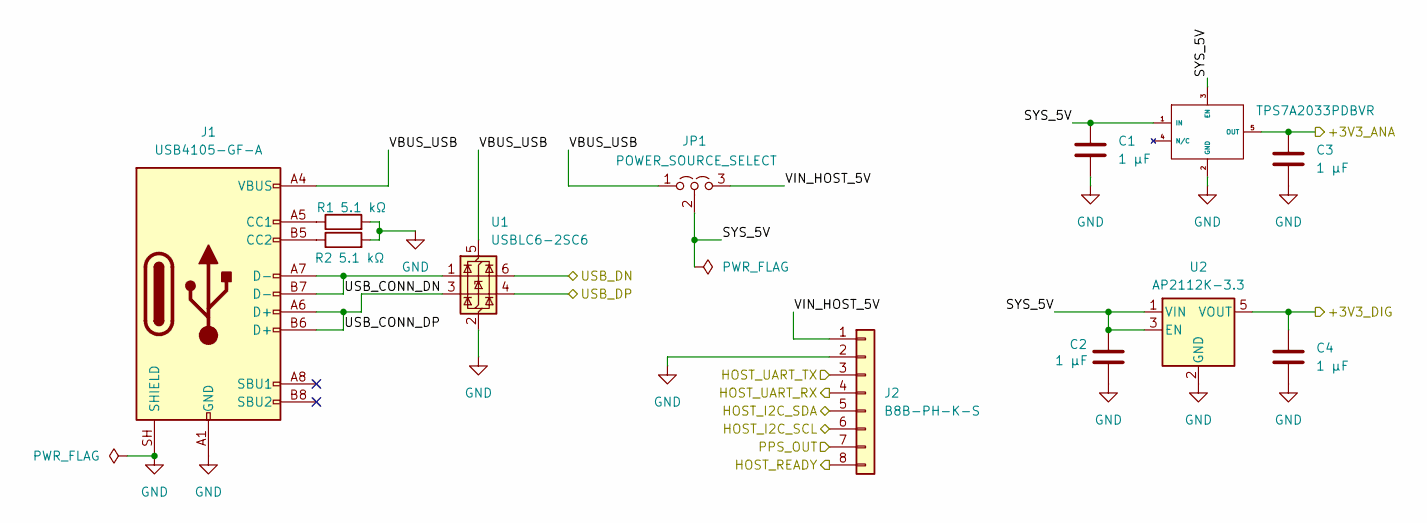
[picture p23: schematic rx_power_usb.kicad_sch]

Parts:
C1, C2, C3, C4: 1 µF; C_0805_2012Metric
J1: USB4105-GF-A; TYPE-C-31-M-14; MPN USB4105-GF-A
J2: B8B-PH-K-S; JST_PH_B8B-PH-K_1x08_P2.00mm_Vertical; MPN B8B-PH-K-S
JP1: POWER_SOURCE_SELECT; PinHeader_1x03_P2.54mm_Vertical; MPN TSW-103-07-G-S
R1, R2: 5.1 kΩ; R_0603_1608Metric
U1: USBLC6-2SC6; SOT-23-6
U2: AP2112K-3.3; SOT-23-5
U3: TPS7A2033PDBVR; SOT-23-5; MPN TPS7A2033PDBVR

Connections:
/+3V3_ANA: C3.1, U3.5 (OUT); also elsewhere on the board
/+3V3_DIG: C4.1, U2.5 (VOUT); also elsewhere on the board
/HOST_I2C_SCL: J2.6; also elsewhere on the board
/HOST_I2C_SDA: J2.5; also elsewhere on the board
/HOST_READY: J2.8; also elsewhere on the board
/HOST_UART_RX: J2.4; also elsewhere on the board
/HOST_UART_TX: J2.3; also elsewhere on the board
/PPS_OUT: J2.7; also elsewhere on the board
/RX_POWER_USB/SYS_5V: C1.1, C2.1, JP1.2 (C), U2.1 (VIN), U2.3 (EN), U3.1 (IN), U3.3 (EN)
/RX_POWER_USB/USB_CONN_DN: J1.A7 (D-), J1.B7 (D-), U1.1 (I/O1)
/RX_POWER_USB/USB_CONN_DP: J1.A6 (D+), J1.B6 (D+), U1.3 (I/O2)
/RX_POWER_USB/VBUS_USB: J1.A4 (VBUS), J1.A9 (VBUS), J1.B4 (VBUS), J1.B9 (VBUS), JP1.1 (A), U1.5 (VBUS)
/RX_POWER_USB/VIN_HOST_5V: J2.1, JP1.3 (B)
/USB_DN: U1.6 (I/O1); also elsewhere on the board
/USB_DP: U1.4 (I/O2); also elsewhere on the board
GND: C1.2, C2.2, C3.2, C4.2, J1.A1 (GND), J1.A12 (GND), J1.B1 (GND), J1.B12 (GND), J1.SH (SHIELD), J2.2, R1.2, R2.2, U1.2 (GND), U2.2 (GND), U3.2 (GND); also elsewhere on the board
unnamed: J1.A5 (CC1), R1.1
unnamed: J1.B5 (CC2), R2.1

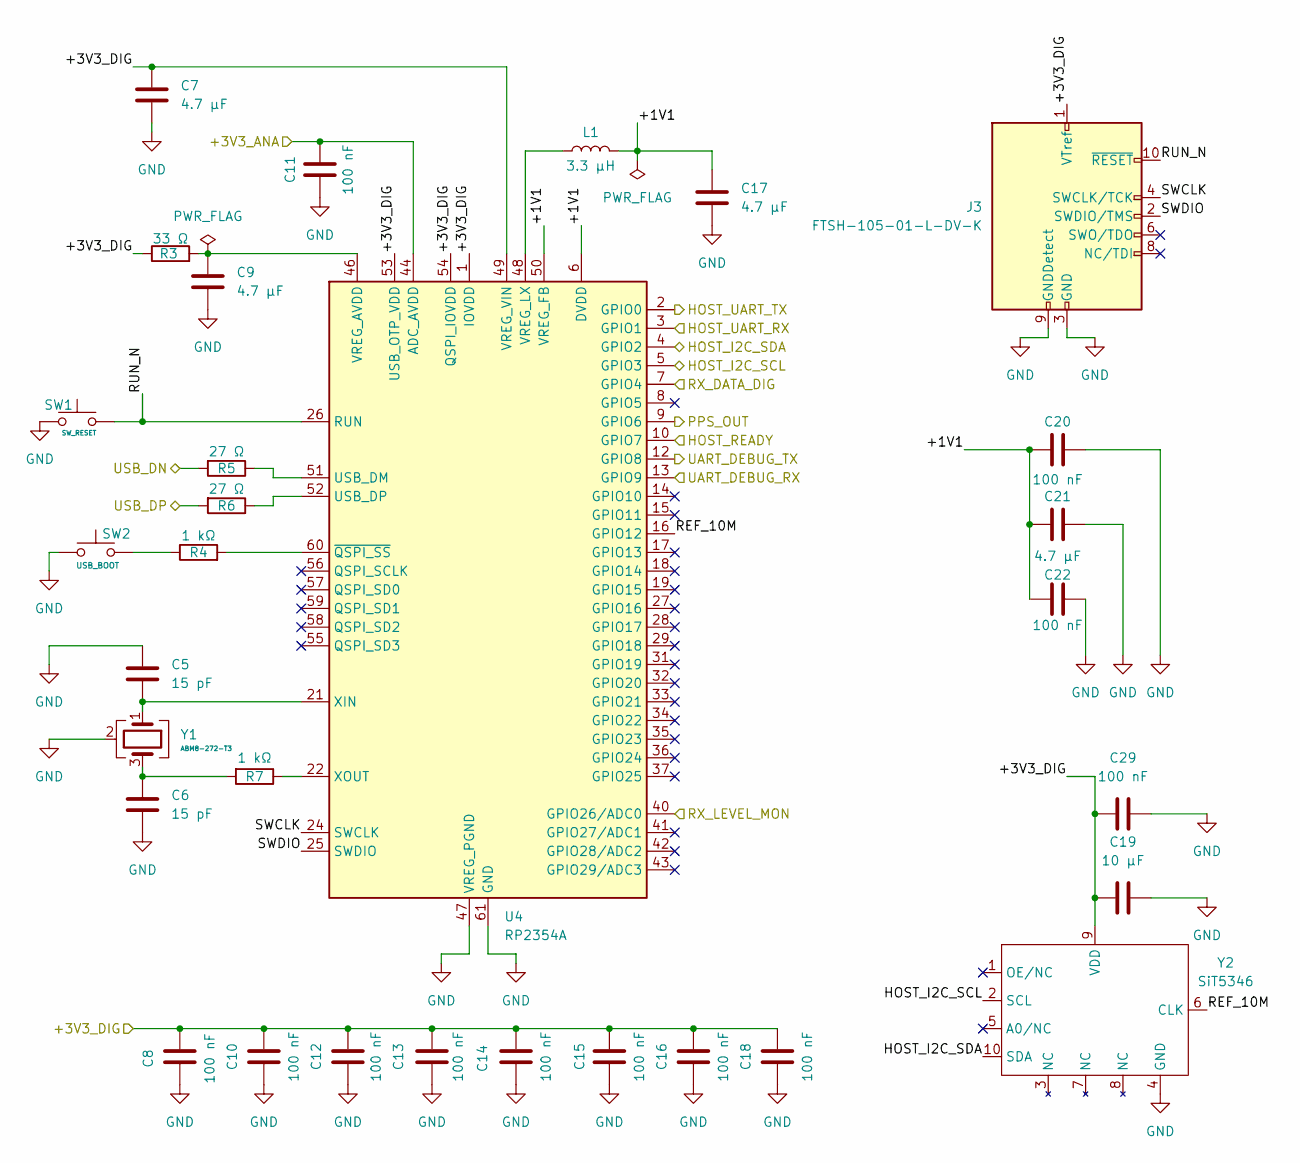
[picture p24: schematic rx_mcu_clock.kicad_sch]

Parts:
C5, C6: 15 pF; C_0603_1608Metric
C7, C9, C17, C21: 4.7 µF; C_0805_2012Metric
C8, C10, C11, C12, C13, C14, C15, C16, C18, C20, C22, C29: 100 nF; C_0603_1608Metric
C19: 10 µF; C_0805_2012Metric
J3: FTSH-105-01-L-DV-K; MPN FTSH-105-01-L-DV-K
L1: 3.3 µH; AOTA-B201610S3R3-101-T
R3: 33 Ω; R_0603_1608Metric
R4, R7: 1 kΩ; R_0603_1608Metric
R5, R6: 27 Ω; R_0603_1608Metric
SW1: SW_RESET; SW_SPST_PTS645Sx43SMTR92
SW2: USB_BOOT; SW_SPST_PTS645Sx43SMTR92
U4: RP2354A; QFN-60-1EP_7x7mm_P0.4mm_EP3.4x3.4mm_ThermalVias
Y1: ABM8-272-T3; ABM8-272-T3_3225; MPN ABM8-272-T3
Y2: SiT5346; SiT5346_5.0x3.2mm_10L; MPN TBD - SiT5346 10MHz 3.3V LVCMOS DCTCXO; JLCPCB Part TBD - Global Sourcing if not stocked

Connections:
/+3V3_ANA: C11.2, U4.44 (ADC_AVDD); also elsewhere on the board
/+3V3_DIG: C7.1, C8.2, C10.2, C12.2, C13.2, C14.2, C15.2, C16.2, C18.2, C19.1, C29.1, J3.1 (VTref), R3.1, U4.1 (IOVDD), U4.11 (IOVDD), U4.20 (IOVDD), U4.30 (IOVDD), U4.38 (IOVDD), U4.45 (IOVDD), U4.49 (VREG_VIN), U4.53 (USB_OTP_VDD), U4.54 (QSPI_IOVDD), Y2.9 (VDD); also elsewhere on the board
/HOST_I2C_SCL: U4.5 (GPIO3), Y2.2 (SCL); also elsewhere on the board
/HOST_I2C_SDA: U4.4 (GPIO2), Y2.10 (SDA); also elsewhere on the board
/HOST_READY: U4.10 (GPIO7); also elsewhere on the board
/HOST_UART_RX: U4.3 (GPIO1); also elsewhere on the board
/HOST_UART_TX: U4.2 (GPIO0); also elsewhere on the board
/PPS_OUT: U4.9 (GPIO6); also elsewhere on the board
/RX_DATA_DIG: U4.7 (GPIO4); also elsewhere on the board
/RX_LEVEL_MON: U4.40 (GPIO26/ADC0); also elsewhere on the board
/RX_MCU_CLOCK/+1V1: C17.1, C20.1, C21.1, C22.2, L1.2, U4.6 (DVDD), U4.23 (DVDD), U4.39 (DVDD), U4.50 (VREG_FB)
/RX_MCU_CLOCK/REF_10M: U4.16 (GPIO12), Y2.6 (CLK)
/RX_MCU_CLOCK/RUN_N: J3.10 (~RESET), SW1.1, U4.26 (RUN)
/RX_MCU_CLOCK/SWCLK: J3.4 (SWCLK/TCK), U4.24 (SWCLK)
/RX_MCU_CLOCK/SWDIO: J3.2 (SWDIO/TMS), U4.25 (SWDIO)
/UART_DEBUG_RX: U4.13 (GPIO9); also elsewhere on the board
/UART_DEBUG_TX: U4.12 (GPIO8); also elsewhere on the board
/USB_DN: R5.2; also elsewhere on the board
/USB_DP: R6.2; also elsewhere on the board
GND: C5.1, C6.2, C7.2, C8.1, C9.2, C10.1, C11.1, C12.1, C13.1, C14.1, C15.1, C16.1, C17.2, C18.1, C19.2, C20.2, C21.2, C22.1, C29.2, J3.3 (GND), J3.5 (GND), J3.9 (GNDDetect), SW1.2, SW2.1, U4.47 (VREG_PGND), U4.61 (GND), Y1.2 (G), Y1.4 (G), Y2.4 (GND); also elsewhere on the board
unnamed: C6.1, R7.2, Y1.3
unnamed: R4.1, SW2.2
unnamed: R5.1, U4.51 (USB_DM)
unnamed: R6.1, U4.52 (USB_DP)
unnamed: C9.1, R3.2, U4.46 (VREG_AVDD)
unnamed: L1.1, U4.48 (VREG_LX)
unnamed: C5.2, U4.21 (XIN), Y1.1
unnamed: R7.1, U4.22 (XOUT)
unnamed: R4.2, U4.60 (~QSPI_SS)

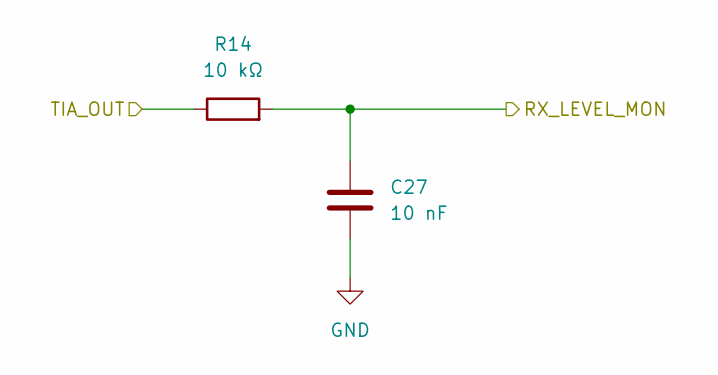
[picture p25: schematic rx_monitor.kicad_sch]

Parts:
C27: 10 nF; C_0603_1608Metric
R14: 10 kΩ; R_0603_1608Metric

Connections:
/RX_LEVEL_MON: C27.1, R14.2; also elsewhere on the board
/TIA_OUT: R14.1; also elsewhere on the board
GND: C27.2; also elsewhere on the board

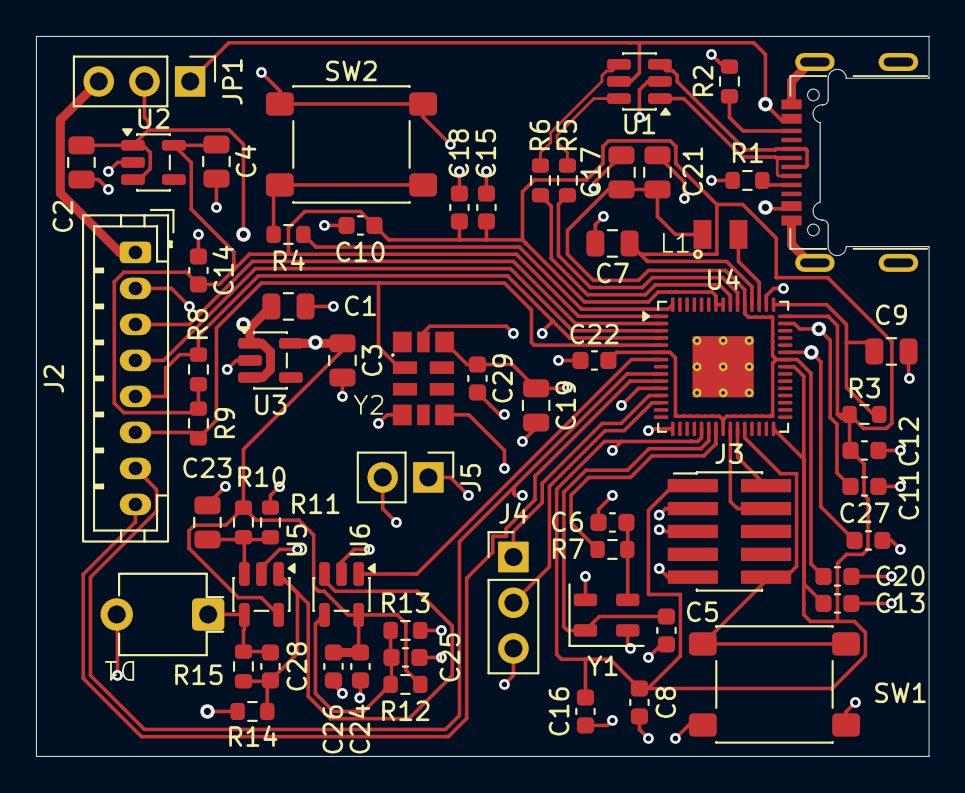
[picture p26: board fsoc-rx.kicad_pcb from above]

Board: 4 copper layers, 49.6 x 40.0 mm, 62 parts (0 on the bottom side), 40 nets.

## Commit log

2026-09-03 setting library preferences
    [fsoc-rx.kicad_pcb, fsoc-rx.kicad_sch, fsoc-tx.kicad_pcb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]
2026-09-03 attach official RP2350/4A libraries
2026-09-03 ASTX-H11 symbol schematics
    [fsoc-tx.kicad_sch]
2026-09-03 ignore kicad temporary and history files
2026-09-04 ASTX-H11 footprint and readme updates
2026-09-04 linking astx symbol to footprint
2026-09-04 general schematic tikz diagrams and code
2026-09-04 BPW34_Vishay footprint
2026-09-04 USB4105 symbol and footprint
2026-09-04 host connector
2026-09-05 TX ROOT: MCU clock and POWER USB
    [fsoc-tx.kicad_sch, tx_laser.kicad_sch, tx_mcu_clock.kicad_sch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]
2026-09-10 TX ROOT: laser + host IO
    [fsoc-tx.kicad_sch, tx_host_io.kicad_sch, tx_laser.kicad_sch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]
2026-09-10 ERC error excluded: TPS22919 QOD tied to VOUT intentionally
    [tx_mcu_clock.kicad_sch, tx_power_usb.kicad_sch]
2026-09-10 RX ROOT: power USB
    [fsoc-rx.kicad_sch, rx_power_usb.kicad_sch]
2026-09-10 RX ROOT: MCU clock
    [fsoc-rx.kicad_sch, rx_mcu_clock.kicad_sch]
2026-09-10 RX ROOT: HOST IO
    [fsoc-rx.kicad_sch, rx_host_io.kicad_sch, rx_mcu_clock.kicad_sch]
2026-09-10 RX ROOT: monitor
    [fsoc-rx.kicad_sch, rx_monitor.kicad_sch, rx_optical_afe.kicad_sch]
2026-09-10 RX ROOT: optical AFE
    [fsoc-rx.kicad_sch, rx_host_io.kicad_sch, rx_mcu_clock.kicad_sch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]
2026-09-10 RX: footprint assignments
    [rx_host_io.kicad_sch, rx_mcu_clock.kicad_sch, rx_monitor.kicad_sch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]
2026-09-10 TX: fixing unassigned footprints
    [tx_host_io.kicad_sch, tx_laser.kicad_sch, tx_mcu_clock.kicad_sch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]
2026-09-12 TX PCB: checkpoint
    [fsoc-tx.kicad_pcb]
2026-09-12 TX PCB: checkpoint (almost finsihed)
    [fsoc-tx.kicad_pcb]
2026-09-13 TX PCB: checkpoint (error: non-plated through holes of GCT USB4105 has 0.194mm distance of the copper pads while the board steup is set to 0.25mm.. waiting approval)
    [fsoc-tx.kicad_pcb]
2026-09-13 TX PCB: fixing board setup (stackups)
    [fsoc-tx.kicad_pcb]
2026-09-13 TX PCB: DONE
    [fsoc-tx.kicad_pcb, fsoc-tx.kicad_sch, tx_mcu_clock.kicad_sch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]
2026-09-14 TX PCB: U3 footprint changed to the thermal vias version
    [fsoc-tx.kicad_pcb, tx_mcu_clock.kicad_sch]
2026-09-15 RX PCB
    [fsoc-rx.kicad_pcb, fsoc-rx.kicad_sch, rx_mcu_clock.kicad_sch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]
2026-09-17 Switching ASTX-H11 to SiT5346 and SiT5346 datasheet
    [tx_mcu_clock.kicad_sch]
2026-09-18 SiT5346 ordering code updated
    [fsoc-tx.kicad_pcb]
2026-09-18 RX PCB: SiT5346
    [fsoc-rx.kicad_pcb, fsoc-rx.kicad_sch, rx_host_io.kicad_sch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]
2026-09-18 manufacturer part number for Sit5346
    [rx_mcu_clock.kicad_sch, tx_host_io.kicad_sch, tx_mcu_clock.kicad_sch]
2026-09-18 Manufacturing files
    [FSOC_TX_BOM.csv, fsoc-rx.csv, fsoc-rx.kicad_pcb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]
2026-10-19 tx gerbers zip file
2026-11-04 gerber zip files
